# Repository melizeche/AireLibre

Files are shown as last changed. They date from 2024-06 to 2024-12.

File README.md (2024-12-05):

# AireLibre

## ¿Qué es AireLibre?

AireLibre es una respuesta de la comunidad a la necesidad de saber sobre la calidad del aire de manera libre, colaborativa y descentralizada.

## Razón de ser

En resumen es responder a: Quiero salir a trotar ¿Puedo ahora o me va a hacer mal?

## Proyectos bajo el «paraguas» de AireLibre

AireLibre es un conjunto de proyectos e iniciativas, algunas como:

* Red Descentralizada de Aire Libre(**ReDAL**): La red de sensores de calidad de aire.
* [Linka: El Backend y API que recibe las mediciones de los sensores](https://github.com/tchx84/linka)
* [Linka Firmware](https://github.com/garyservin/linka-firmware/): Firmware de arduino
* [LinkaBot:](https://github.com/melizeche/linkaBot) el bot de twitter que postea cada 2 horas [@KoaNdeAire](https://twitter.com/KoaNdeAire)
* [AQmap: Mapa web en Go](https://github.com/matiasinsaurralde/aqmap)
* [App Android](https://github.com/LucasGinard/AireLibre-Android) Disponible en la -> [PlayStore](https://play.google.com/store/apps/details?id=com.lucasginard.airelibre)
* [App iOS](https://github.com/LucasGinard/AireLibre-iOS) Disponible en la -> [AppStore](https://apps.apple.com/us/app/airelibre-calidad-del-aire/id6446297783)

## FAQ

### ¿Existen otras iniciativas similares?

Si, pero no están abiertas a la colaboración de la comunidad ni son de código abierto.

### ¿Puedo sumarme a la red?

Claro, sin problemas!

### Quiero sumarme a la red, ¿qué necesito?

Básicamente un sensor que se comunique con Linka, nuestro backend.

### Quiero construir un sensor, ¿qué necesito?

#### Materiales necesarios:
* Sensor de calidad del aire Plantpower PMS7003 (asegurarse de que venga con la placa adaptadora) [Aliexpress](https://www.aliexpress.com/item/32784279004.html) [Ebay](https://www.ebay.com/itm/High-Precision-Laser-Dust-Sensor-Module-PM2-5-PM10-for-PMS7003-Cable-for-Arduino/303452433279) [Amazon](https://www.amazon.com/DSLE-Digital-PLANTOWER-PMS7003-Adapter/dp/B08M2F4B9R)
* Placa ESP8266, nosotros usamos la Wemos D1 mini [Aliexpress](https://www.aliexpress.com/item/32787418018.html) [Ebay](https://www.ebay.com/itm/D1-Mini-NodeMcu-4M-bytes-Lua-WIFI-Development-Board-ESP8266-by-WeMos/224207727199)
* Caja plástica exterior 100x100mm [Luminotecnia](https://www.luminotecnia.com.py/producto/975/caja-exterior-plastica-de-conexion-100x100)
* Prensacables (opcional) [Luminotecnia](https://www.luminotecnia.com.py/producto/3720/prensacable-pg-11)
* Cable micro USB
* Cargador USB

#### Herramientas necesarias
* Soldador 40W
* Estaño
* Pinzas para corte
* Destornilladores
* (Opcional) [Soporte para soldar](docs/docs/Welding_Support.STL)

#### Guía de armado
* [Guía rápida](docs/GuiaRapida.pdf)
* [Presentación del Taller de Armado](docs/Presentacion-TallerSensoresCalidadDelAire.pdf)
* [Flashear el firmware a la última versión](https://github.com/garyservin/linka-firmware/tree/master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)

### ¿Por qué tantos proyectos diferentes?

Es una iniciativa descentralizada y medio va por ese lado.

### ¿Puedo extender/sumar proyectos a AireLibre?

Claro, es una iniciativa comunitaria, si querés crear alguna solución, frontend, bot o lo que se te ocurra podés hacerlo, avisanos y lo agregamos al readme.

### ¿Puedo crear mi propia red?

Claro, la licencia te permite, si por alguna razón sumarte a la Red Descentralizada de AireLibre no soluciona tus necesidades podes clonar los repositorios adaptarlos a tu necesidad.

### ¿Es de uso profesional/industrial/científico/militar?

No.

### ¿Los sensores son calibrados en Suiza?

No, en Luque.

### ¿Por qué Linka?

¿Nunca viste Capitán Planeta? Linka era la planetaria del viento.


## Contribuir

Si es un feature nuevo antes de contribuir preguntá en los issues si tu funcionalidad es necesitada por el proyecto

1. Forkeá el proyecto!
2. Creá tu feature branch: `git checkout -b my-new-feature`
3. Commiteá tus cambios: `git commit -am 'Add some feature'`
4. Pusheá a tu branch: `git push origin my-new-feature`
5. Enviá un pull request al branch `main`
   
## Licencia

[GNU Affero General Public License](LICENSE)

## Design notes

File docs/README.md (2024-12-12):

# Documentación para el armado de sensores de calidad del aire de AireLibre

## 1. Guía Rápida de Armado y Presentación Educativa

Ambos archivos, **GuiaRapida.pdf** y **Presentacion-TallerSensoresCalidadAire.pdf**, pueden ser utilizados para guiar una clase práctica sobre el armado de sensores de calidad del aire.

- **GuiaRapida.pdf**: Esta es una guía concisa con los pasos detallados para la construcción de los sensores, diseñada para facilitar el armado de los mismos durante una clase. Sirve como un manual de referencia rápida para los participantes mientras siguen las instrucciones de montaje.

- **Presentacion-TallerSensoresCalidadAire.pdf**: Esta presentación educativa acompaña el proceso de armado, proporcionando una explicación más profunda sobre el funcionamiento de los sensores, los materiales necesarios y los pasos de configuración. Es útil para explicar la teoría detrás de los sensores y asegurar que los participantes comprendan su diseño y operación antes de comenzar el ensamblaje práctico.

Juntos, estos materiales ofrecen tanto un recurso visual como una guía práctica para facilitar la enseñanza del armado de los sensores, asegurando que los participantes comprendan tanto el proceso como la tecnología detrás de los sensores de calidad del aire.

## 2. Archivos de Modelos 3D

Se incluyen tres archivos de modelos 3D para imprimir, que sirven como soporte para las placas de los sensores:

- **Welding_Support.SLDPRT**: Archivo del modelo 3D en formato SolidWorks.
- **Welding_Support.STEP**: Archivo del modelo 3D en formato STEP.
- **Welding_Support.STL**: Archivo del modelo 3D en formato STL.

ImageToStl com_welding_support stl

Estos archivos están diseñados para facilitar la fabricación de los soportes de las placas de los sensores mediante impresión 3D.

---

## Agradecimientos
Los siguientes documentos fueron generados por **[@rrojasPy](https://github.com/rrojasPy)** para el Taller de Sensores de Calidad del Aire, organizado por [**Proyecto Respira**](https://github.com/ProyectoRespira/), **AireLibre**,  y [**Girls Code**](https://github.com/GirlsCodePy).

Este taller fue posible gracias al apoyo de la **Fundación Mozilla** a través del [Mozilla Technology Fund](https://github.com/MozillaFoundation/mozilla-technology-fund).
¡Agradecemos a todos los participantes del primer taller donde usamos estos materiales!

00 Foto grupal

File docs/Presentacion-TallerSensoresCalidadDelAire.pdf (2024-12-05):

# Taller sensores Calidad del Aire

# 30-Nov-2024

1. Introducción a la electrónica básica.

# - Voltaje (V)

## Es la fuerza que impulsa los electrones a través de un circuito. Se mide

en voltios (V).

# Corriente (I)

## Es el flujo de electrones en un circuito y se mide en

amperios (A).

# Resistencia (R)

Es la oposición al flujo
de corriente, medida en
ohmios (Ω)

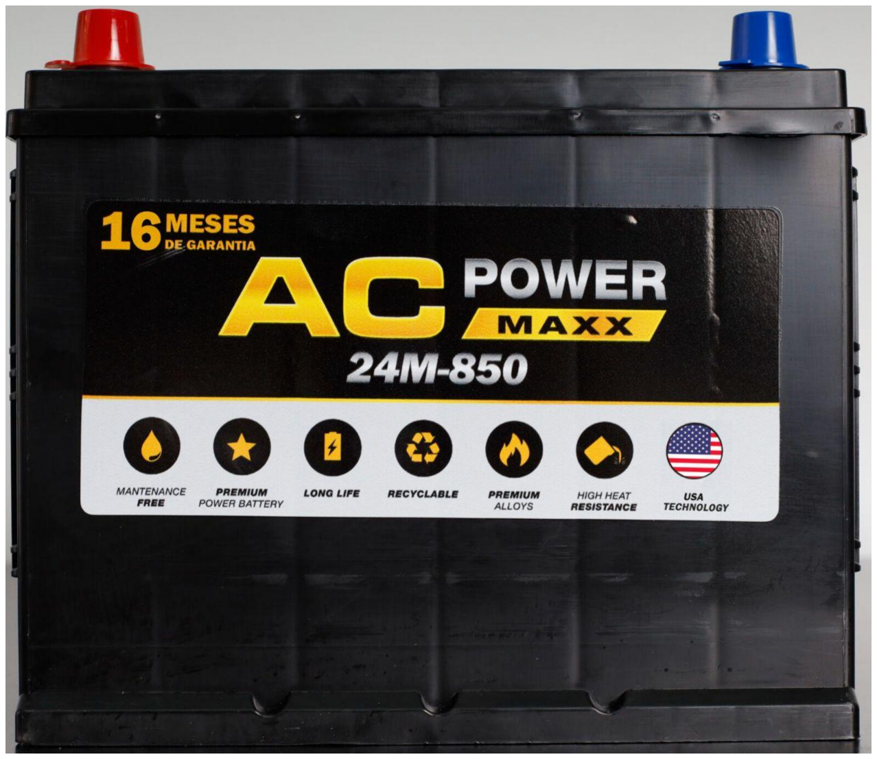
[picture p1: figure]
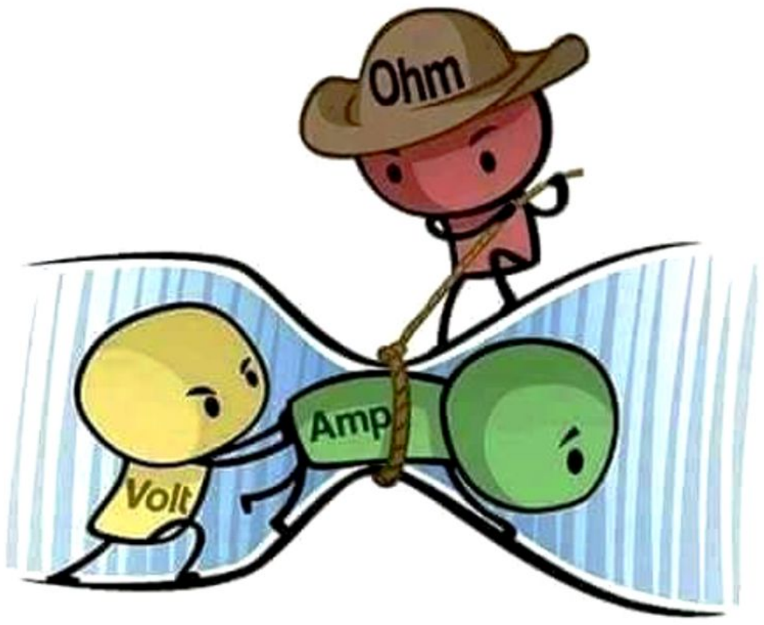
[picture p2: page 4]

1. Introducción a la electrónica básica.

# 1.1. Herramientas

# Herramientas

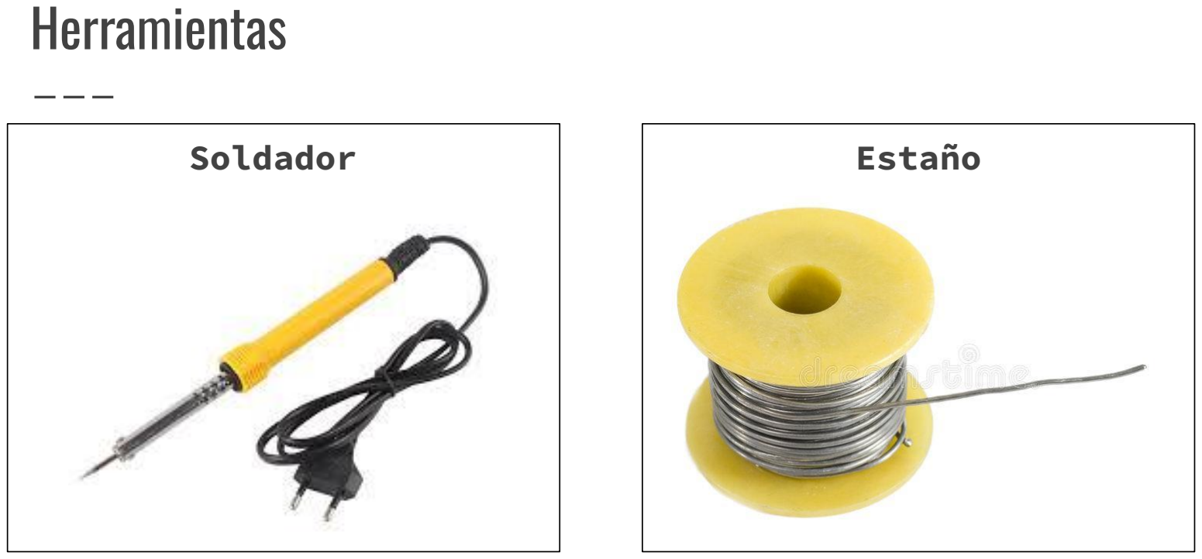
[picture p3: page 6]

Soldador | Estaño

Desoldador | Pinzas y Alicates | Esponjas

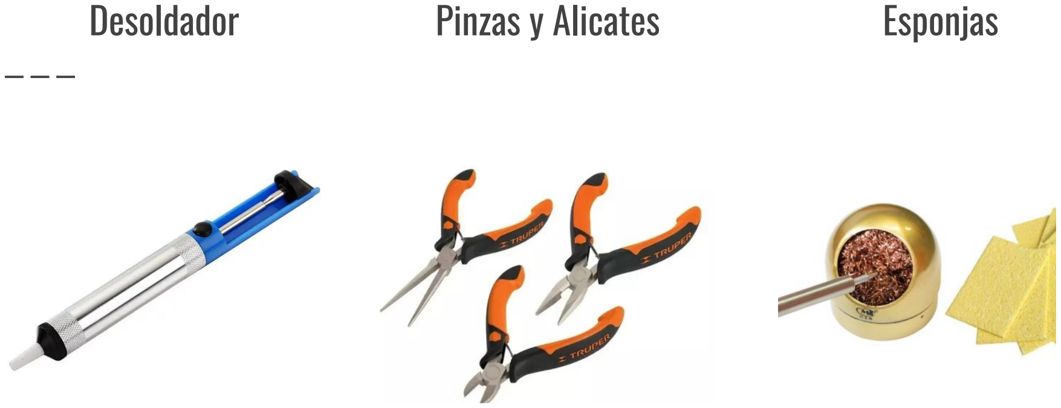
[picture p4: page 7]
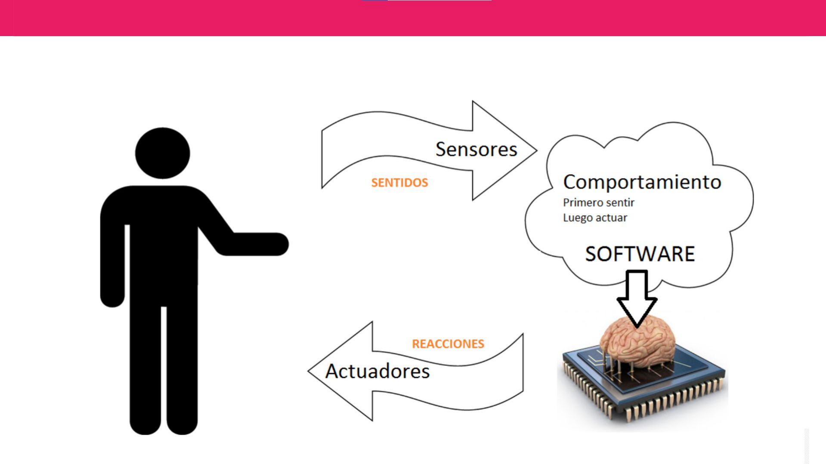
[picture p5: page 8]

# Sensores

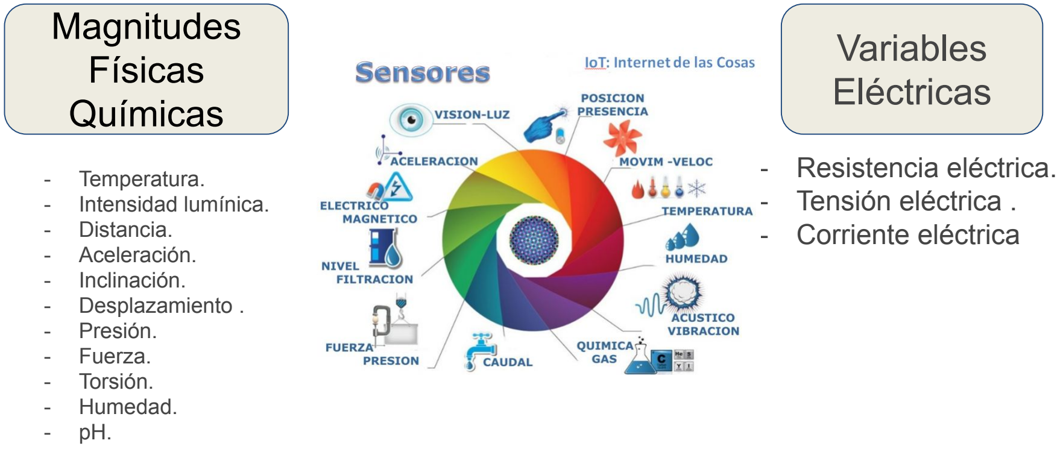
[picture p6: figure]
Magnitudes Físicas Químicas; Variables Eléctricas

- | Temperatura. - | Intensidad lumínica. - | Distancia. - | Aceleración. - | Inclinación. - | Desplazamiento . - | Presión. - | Fuerza. - | Torsión. - | Humedad. - | pH.
- | Resistencia eléctrica. - | Tensión eléctrica . - | Corriente eléctrica

# Actuador

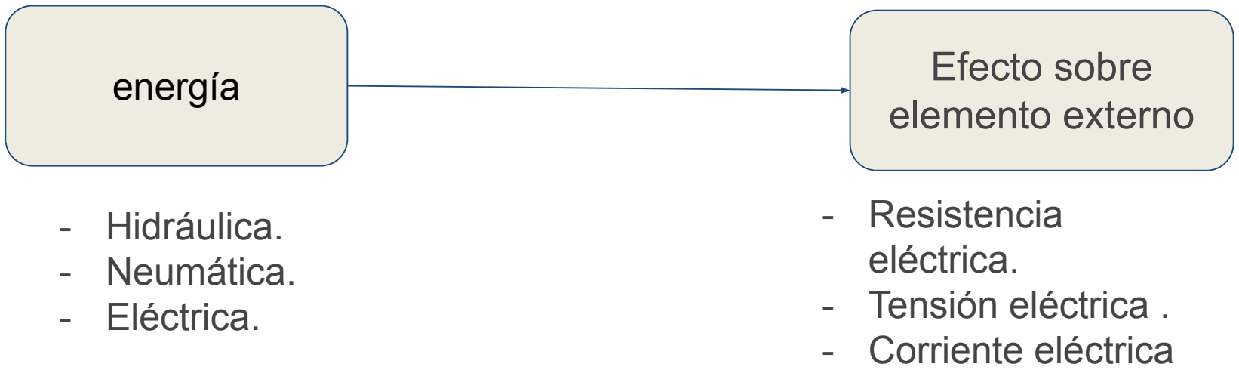
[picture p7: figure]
energía; Efecto sobre; elemento externo; - Hidráulica. - Neumática. - Eléctrica.; - Resistencia eléctrica. - Tensión eléctrica . - Corriente eléctrica

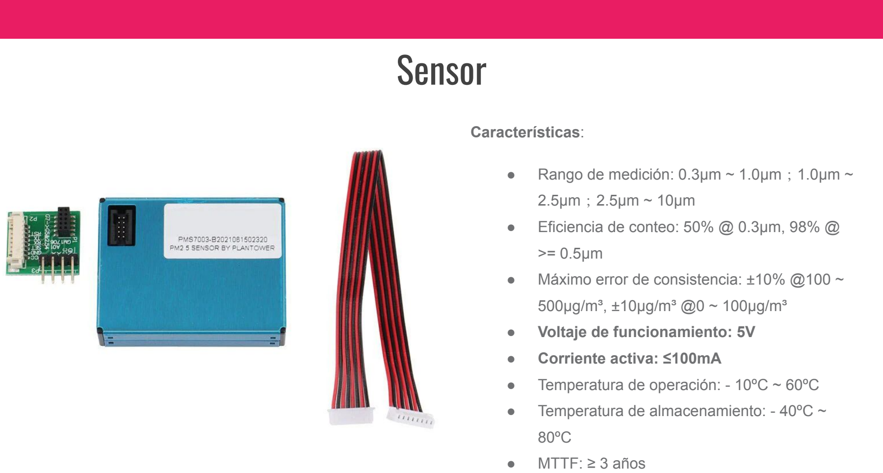
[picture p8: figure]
Sensor; Características:; ● Voltaje de funcionamiento: 5V; ● Corriente activa: ≤100mA; ● MTTF: ≥ 3 años

- Rango de medición: 0.3μm ~ 1.0μm；1.0μm ~
- Eficiencia de conteo: 50% @ 0.3μm, 98% @
- Máximo error de consistencia: ±10% @100 ~
- Temperatura de operación: - 10ºC ~ 60ºC
- Temperatura de almacenamiento: - 40ºC ~

PMS 7003 (https://download.kamami.pl/p564008-PMS7003%20series%20data%20manua_English_V2.5.pdf)

# Material particulado 10μm

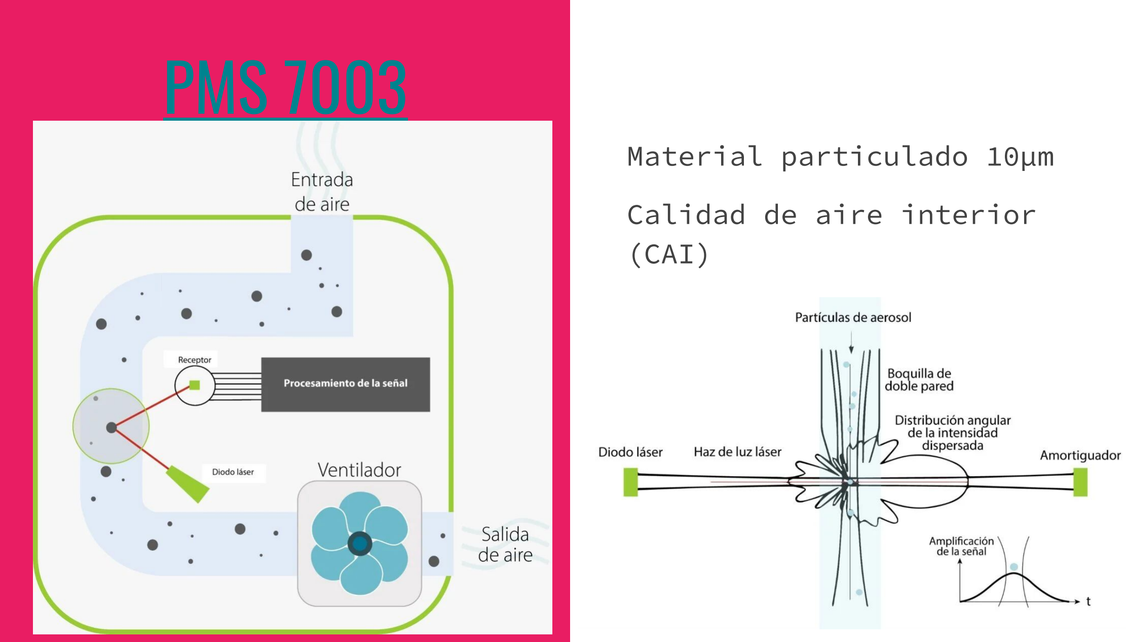
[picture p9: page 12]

# Calidad de aire interior (CAI)

# Micro Controlador

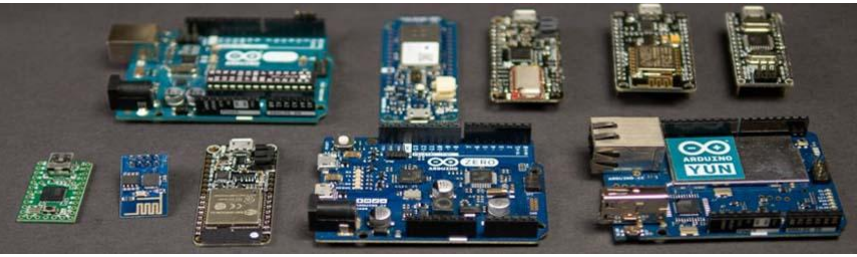
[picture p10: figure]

# Sensor

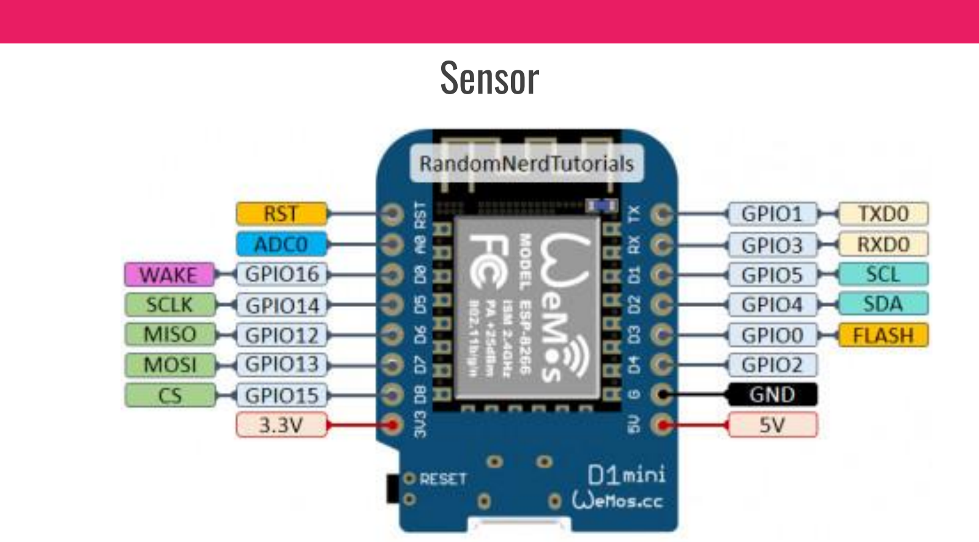
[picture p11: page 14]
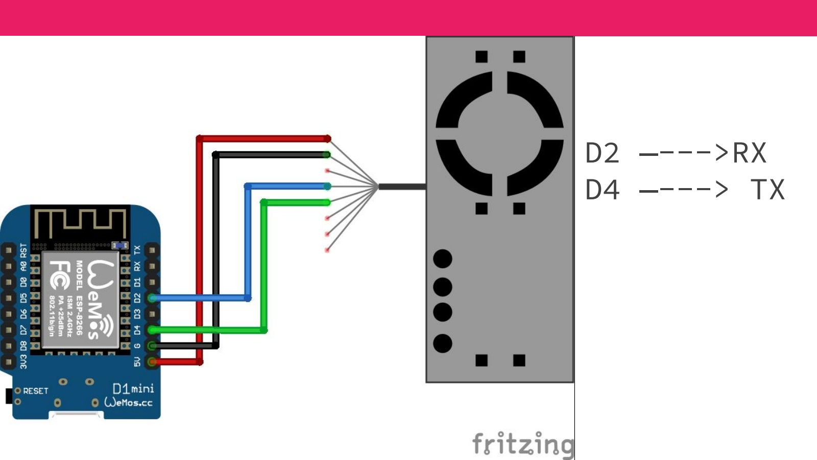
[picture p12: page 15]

# D2 —--->RX D4 —---> TX

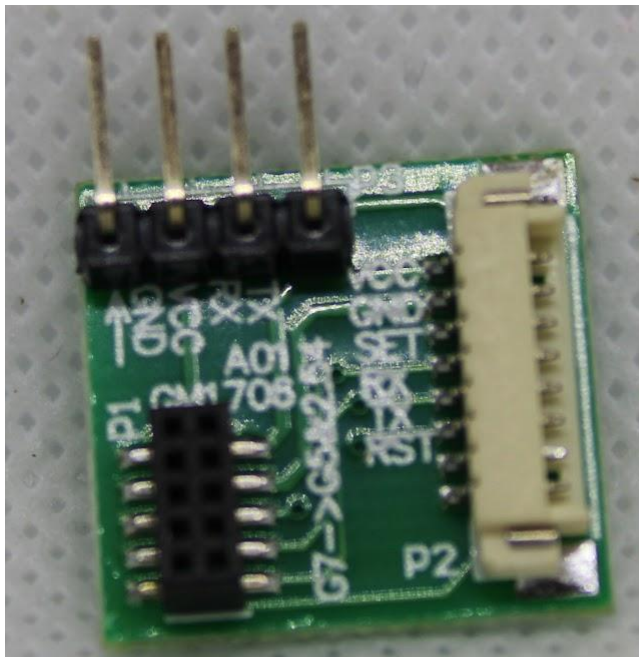
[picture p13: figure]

2. Ensamblaje y soldadura de componentes.

Soporte para soldar | Pines | ESP8266

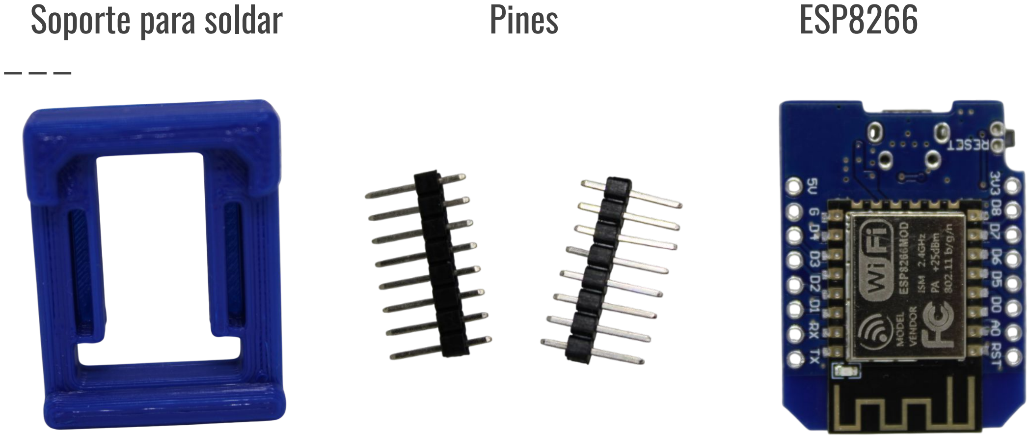
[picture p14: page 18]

PMS 7003 | Cable MicroUSB | Caja 10 x 10 cm

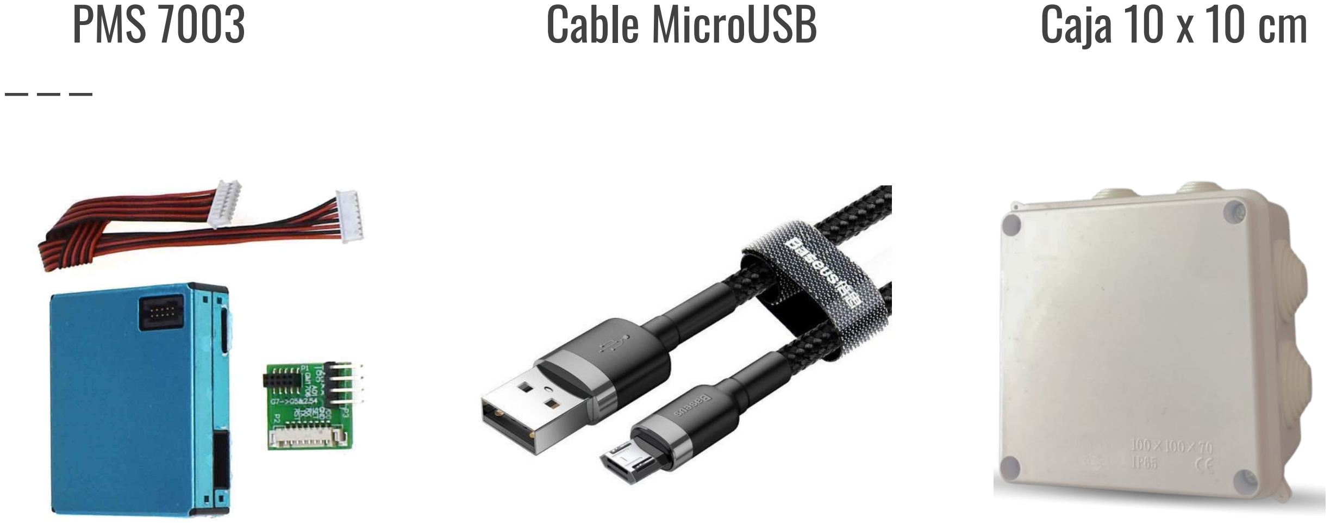
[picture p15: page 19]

# SOLDADURA

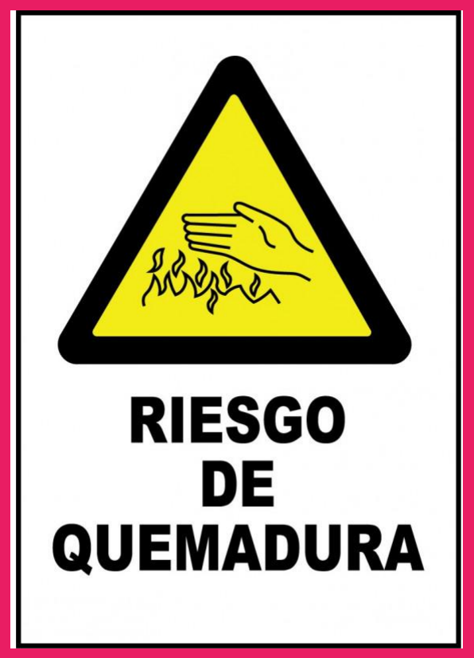
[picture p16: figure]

# Manejar con cuidado para

evitar quemaduras.

# - Asegúrate de que la

punta esté limpia,

# usando una esponja húmeda o limpiador de

soldador.

# - Coloca la punta en el área a soldar para

calentarla.

# - Aplica una pequeña cantidad de estaño y

retira el soldador.

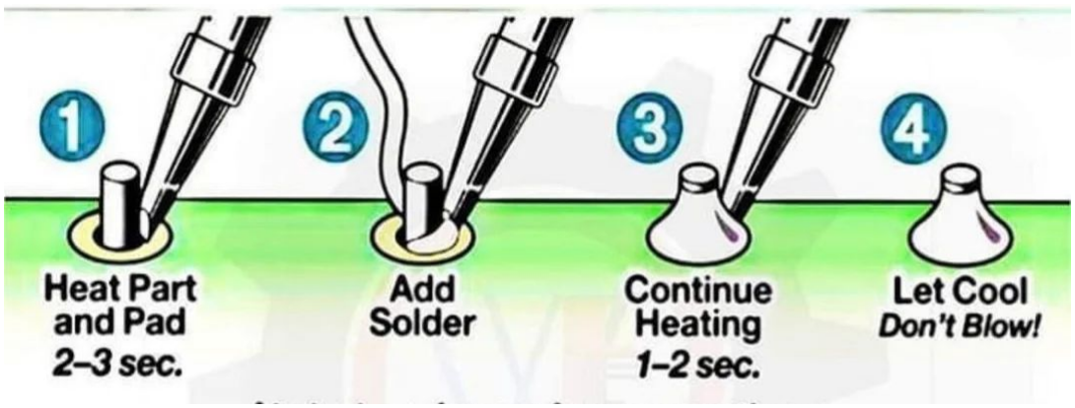
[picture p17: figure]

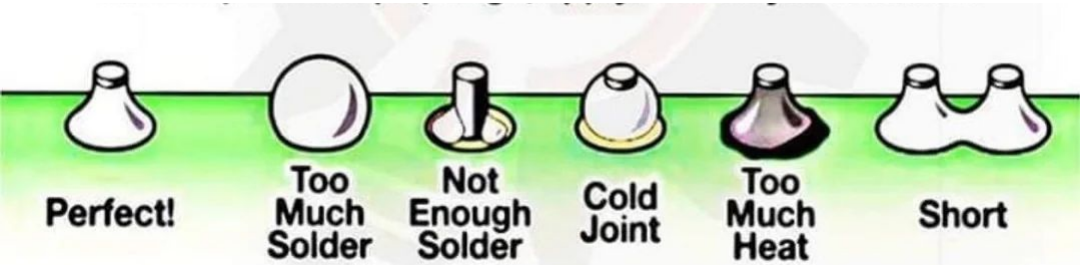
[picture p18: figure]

Soporte ESP8266 | Pines de conexión | Ubicación pines

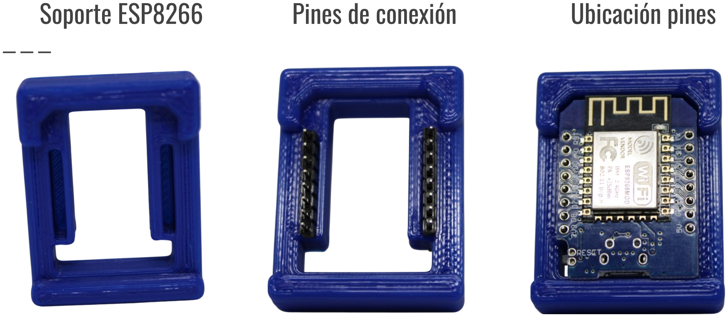
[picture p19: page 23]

# ENLACE

VIDEO (https://drive.google.com/file/d/1pR1Au02UIR5KgAWZWM10eflSMWYjTx47/view?usp=sharing)

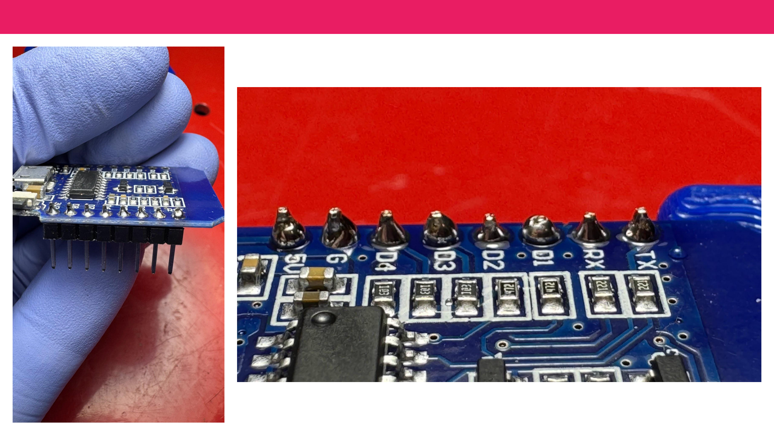
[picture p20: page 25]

# 3. Carga Firmware ESP8266

OPC 1.

# https://linka.servin.dev/

Para todos los SO.

# Navegadores compatibles: - Chrome - Mozilla

# Acceder a la web (https://linka.servin.dev/)

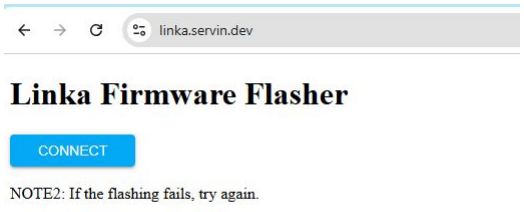
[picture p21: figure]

1. Clic en botón CONNECT.

# 2. Seleccionar puerto USB 3. Seguir los pasos de la web

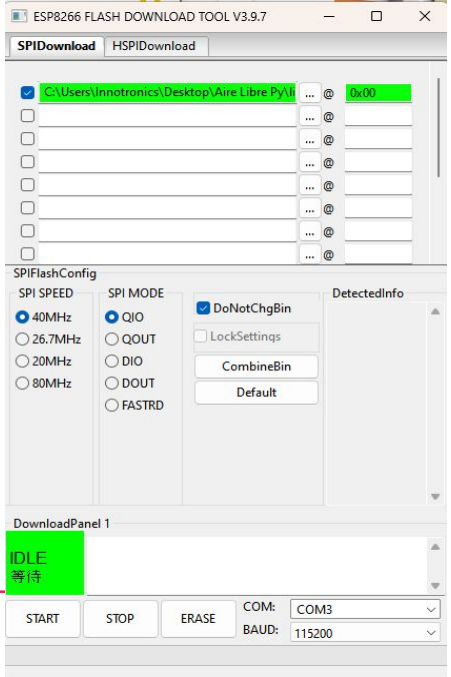
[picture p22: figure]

OPC 2.

# FLASH DOWNLOAD TOOL

# Solo para Windows

Descargar archivo Bin (https://github.com/garyservin/linka-firmware/releases/download/0.3.2/linka-firmware-v0.3.2.bin)

OPC 3.

# esptool

Para todos los SO.

# Se requiere tener

instalado Python.
Se ejecuta en terminal.

# pip install esptool

# esptool.py --chip esp8266

--port | /dev/ttyUSB0 | --baud

# 115200 --before default_reset --after hard_reset write_flash 0x0 linka-firmware-v0.3.2.bin

# /dev/ttyUSB0 Puerto USB LINUX COM4 Puerto USB WINDOWS

Descargar archivo Bin (https://github.com/garyservin/linka-firmware/releases/download/0.3.2/linka-firmware-v0.3.2.bin)

# 4. Configuración y carga del API Key

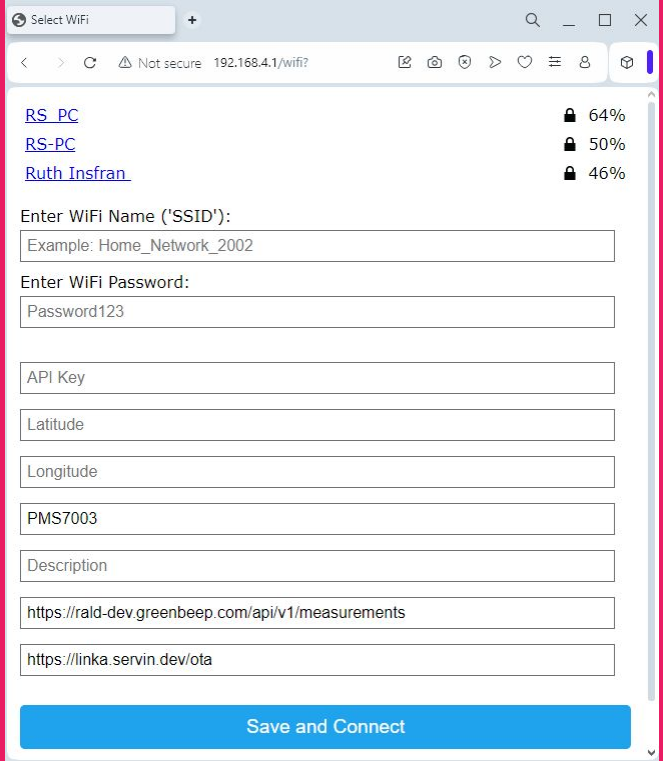
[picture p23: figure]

Conectar a una red Wifi.

# Ej. Linka-b773ec Introductor la API KEY (Solicitar en el grupo de telegram) (https://t.me/AireLibrePy)

Introducir Latitud (https://www.google.com/maps/) | 3 decimales
Introducir Longitud (https://www.google.com/maps/) | 3 decimales

# Introducir Descripción (País/Ciudad/ Barrio/)

# 5. Recomendaciones e instalación final

# 1. Ubicación y Orientación

## Ambiente limpio: Evita colocar

el sensor en áreas con suciedad,

## humedad excesiva o corrientes de

aire fuertes.

## Altura adecuada: Instálalo a una altura representativa para las mediciones, idealmente entre 1 y

2 metros.

## Orientación: El sensor debe instalarse de manera que los puertos de entrada y salida de aire estén despejados para garantizar una correcta

circulación del flujo de aire.

# 2. Montaje

# Usa soportes o carcasas específicas

# Evita la exposición directa al sol o a la

lluvia.

# 3. Mantenimiento

## Tensión de alimentación: Asegúrate de que el sensor esté conectado a un suministro de energía que cumpla con sus

especificaciones.

## Limpieza periódica: Inspecciona los puertos de entrada y salida de aire regularmente para eliminar polvo acumulado que podría

afectar la precisión.

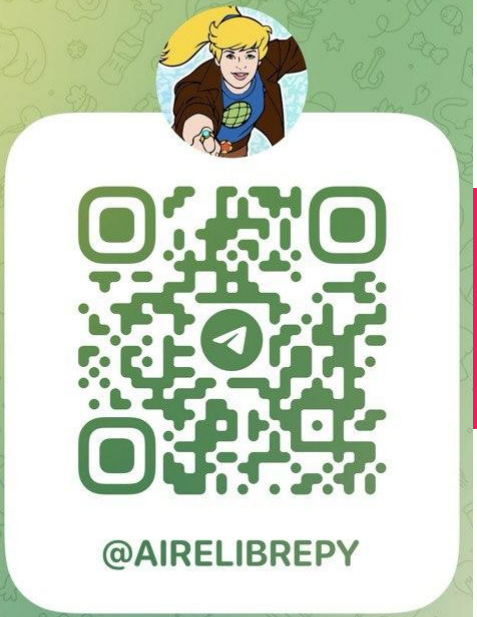
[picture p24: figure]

# Muchas Gracias

# Referencias de materiales e imágenes utilizados

- https://muhendistan.com/direnc-nedir-direnc-cesitleri-nelerdir/
- https://www.electronica.com.py/producto/soldador-60w-220v/
- https://es.dreamstime.com/foto-de-archivo-carrete-del-esta%C3%B1o-para-soldar-image7981260
- https://es.aliexpress.com/item/32812422133.html
- https://porter.com.py/truper-18215-pinzas-mini-3pzs
- https://laboratoriodeprojetosdeeletronica.wordpress.com/2018/07/13/confeccao-de-placas-de-circuito-impresso/ (https://laboratoriodeprojetosdeeletronica.wordpress.com/2018/07/13/confeccao-de-placas-de-circuito-impresso/)
- http://www.broscom.net/wp/internet-de-las-cosas/
- https://especificarmag.com.mx/lo-que-debes-saber-sobre-los-sensores-de-particulas/
- https://www.amazon.sa/-/en/Sensor-PMS7003-Digital-Inculd-Transfer/dp/B0BFCWTLL8
- https://especificarmag.com.mx/lo-que-debes-saber-sobre-los-sensores-de-particulas/
- https://tecnotom.com/arduino/historia/
- https://randomnerdtutorials.com/esp8266-pinout-reference-gpios/
- https://www.luminotecnia.com.py/producto/975/caja-exterior-plastica-de-conexion-100x100
- https://nissei.com/py/cable-usb-a-a-micro-usb-baseus-cafule-negro-50-cm-camklf-ag1
- https://brero.es/shop/peligro/156-cartel-riesgo-de-quemadura.html
- https://www.reddit.com/r/MechanicalKeyboards/comments/gpjlvd/perfect_soldering_steps/
- https://www.extra.com.br/bateria-duracell-9v/b
- https://acpowervzla.com/producto/bateria-ac-power-maxx-modelo-24m-850/
- https://www.caremarc.cl/product/pila-duracell-aa

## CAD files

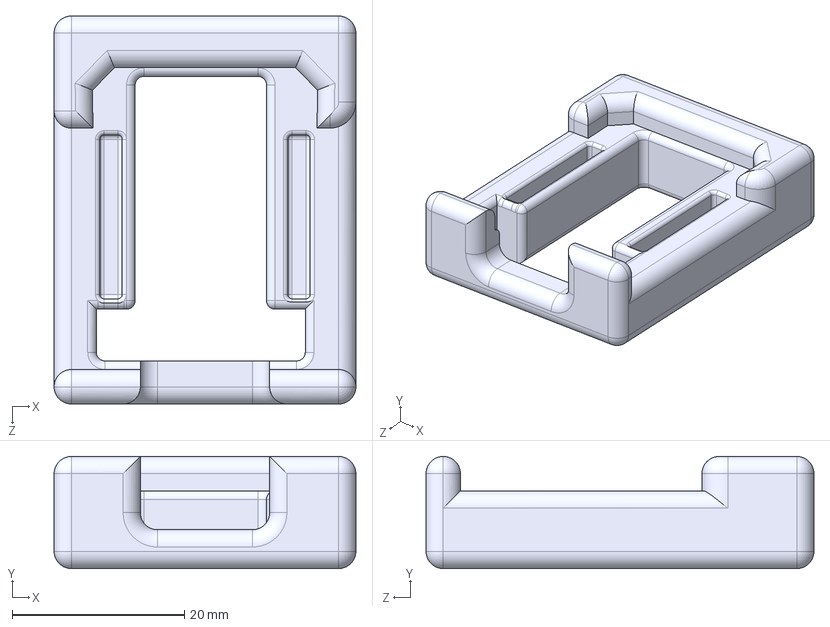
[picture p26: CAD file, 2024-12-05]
docs/Welding_Support.STEP
35.0 x 13.0 x 45.0 mm

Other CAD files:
docs/Welding_Support.SLDPRT
docs/Welding_Support.STL

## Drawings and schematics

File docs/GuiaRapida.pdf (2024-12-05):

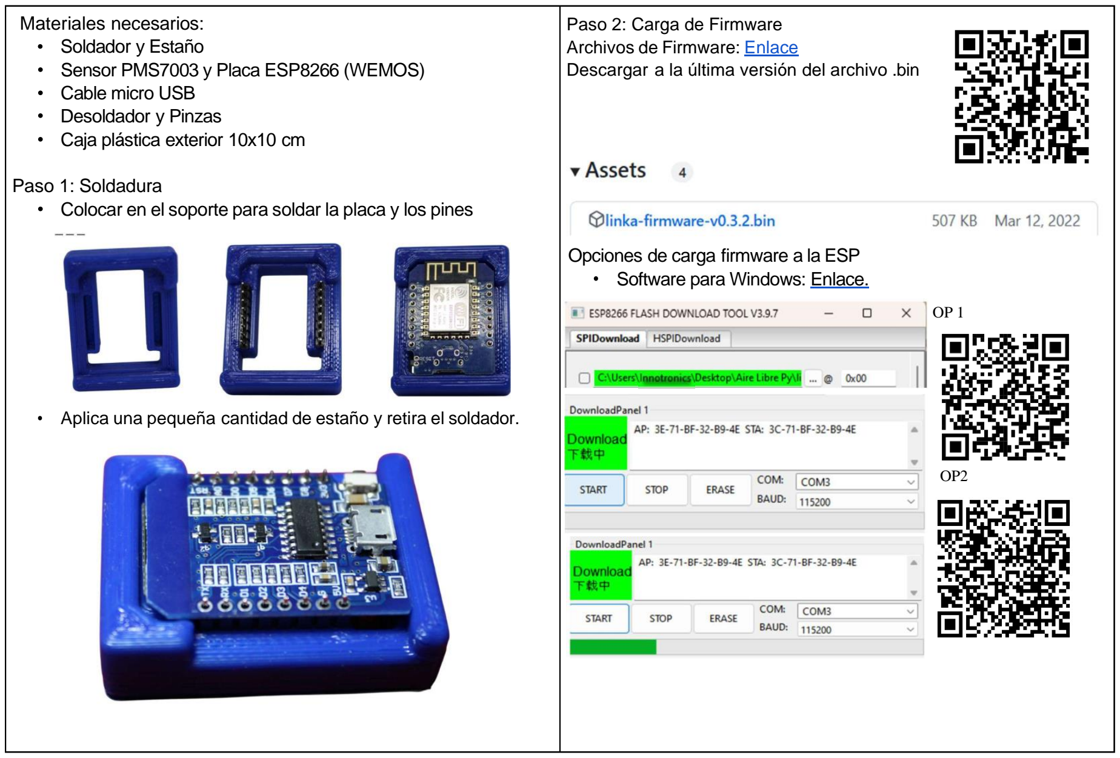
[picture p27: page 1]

OP 1

OP2

Opciones de carga firmware a la ESP Software para Windows: Enlace.

Paso 2: Carga de Firmware
Archivos de Firmware: Enlace
Descargar a la última versión del archivo .bin

Aplica una pequeña cantidad de estaño y retira el soldador.

Materiales necesarios:
Soldador y Estaño
Sensor PMS7003 y Placa ESP8266 (WEMOS) Cable micro USB
Desoldador y Pinzas
Caja plástica exterior 10x10 cm

Paso 1: Soldadura
Colocar en el soporte para soldar la placa y los pines

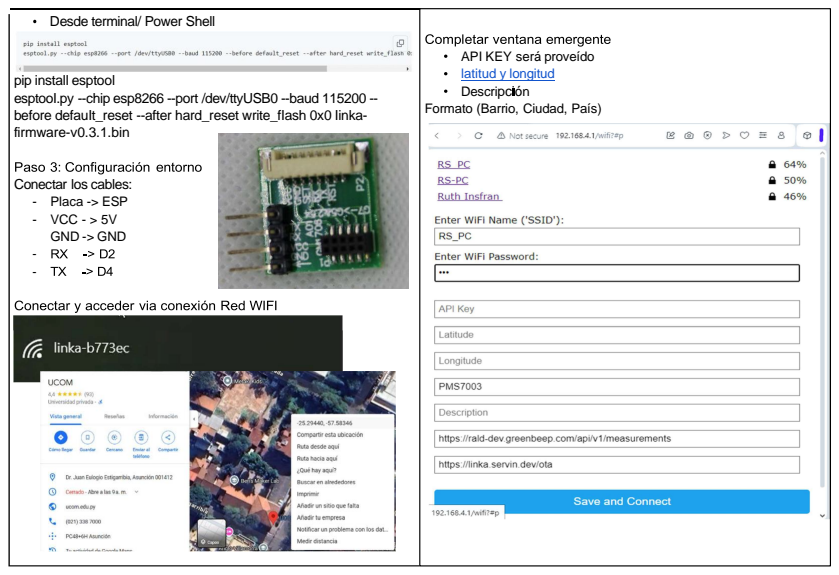
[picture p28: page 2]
Conectar los cables: - Placa -> ESP - VCC - > 5V GND -> GND

Desde terminal/ Power Shell

API KEY será proveído
latitud y longitud
Descripción
Formato (Barrio, Ciudad, País)

pip install esptool
esptooI.py --chip esp8266 --port /dev/ttyUSB0 --baud 115200 --
before defauIt_reset --after hard_reset write_fIash 0x0 Iinka-
firmware-v0.3.1.bin

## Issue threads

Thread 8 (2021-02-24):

Aporte al proyecto

oddure, 2021-02-24:
Buenas, quise aportar al proyecto desarrollando una app con widget (algo parecido al widget del clima, en este caso con los datos de la calidad del aire), de forma que se pueda acceder a los datos de los sensores cercanos a una determinada posición y a la vez estos datos se actualicen automáticamente en el widget cada cierto tiempo. Espero que sea el agrado de ustedes.
Link del proyecto: [https://github.com/oddure/AppWidgetAireLibre](url)

Closed 2021-06-07.

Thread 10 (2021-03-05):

Color sensors icons with corresponding quality color scheme

tchx84, 2021-03-05:
... and hide the popup by default. This will make the map scale much better.

melizeche, 2021-05-27:
is this still an issue?  @tchx84

tchx84, 2021-05-27:
Nope!

Closed 2021-05-27.

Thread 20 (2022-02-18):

Include per-sensor statistics

tchx84, 2022-02-18:
This could be displayed on a separate page to avoid cluttering the current map-review with too much information. e.g., the current map popups could simply display a "see more" button, which would take the user to this separate page that can include:

1. historical maximum values.
2. historical minimum values.
3. historical average values.
4. histogram of all recorded values.

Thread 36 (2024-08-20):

Notificaciones Android

acarrizosa, 2024-08-20:
Buenas! Sería posible que la aplicación de Android eventualmente envíe notificaciones cuando el aire más próximo alcanza el nivel de "no tan bien"?

Gracias!

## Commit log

2020-12-09 Agregar enlace de proyecto
2020-12-14 Add materials for building a sensor
2022-04-05 fetch: Look back one hour to the past
    This will be needed to make FIUNA sensos more
    visible, due to the fact their sensors don't
    update as often as hours.
2024-09-04 Update README.md
    Actualizacion de links de productos de Luminotecnia
2024-09-17 cambio en el botón de modo y deteccion de modo oscurz
2024-12-04 Add atributo para que link se abran en una nueva pestaña
2024-12-05 Added instructional materials for the workshop
    - Presentation on sensors and welding quality (PDF).
    - 3D models of welding support in SLDRT, STEP, and STL formats.
    - Quick guide in (PDF).
    [Welding_Support.SLDPRT, Welding_Support.STEP, Welding_Support.STL]
2024-12-05 Rename 'Materiales Instructivos' directory to 'docs' and rename non ascii character filenames
    [Welding_Support.SLDPRT, Welding_Support.STEP, Welding_Support.STL]
